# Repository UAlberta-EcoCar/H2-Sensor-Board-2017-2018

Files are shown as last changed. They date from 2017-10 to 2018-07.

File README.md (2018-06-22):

# H2-Sensor-(Safety)-Board
Repository for the hydrogen sensor (safety) board and associated code.

This board is responsible for shutting down the FCC system in case of a H2 leak, E-stop button push or remote-kill signal.

Preliminary documentation (to be moved to Wiki): https://drive.google.com/open?id=1S8betwiyb474213RZoNG3XHaL3DfAaQFg7lT7IdTJPk

Folder on Google Drive with other related files: https://drive.google.com/open?id=1GxiV1qDfL8EswHq86x-2SQPqP8KY5xJN

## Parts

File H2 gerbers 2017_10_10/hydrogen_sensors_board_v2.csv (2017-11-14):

Qty | Value | Device | Package | Parts | Description | PROD_ID | VALUE
6 |  | C-USC0603 | C0603 | C3, C4, C5, C6, C7, C8 | CAPACITOR, American symbol
3 |  | LEDCHIPLED_0805 | CHIPLED_0805 | LED1, LED2, LED3 | LED
1 |  | PINHD-1X3 | 1X03 | JP4 | PIN HEADER
2 | 100k | RESISTOR0603-RES | 0603-RES | R11, R12 | Resistor
7 | 10k | RESISTOR0603-RES | 0603-RES | R1, R5, R6, R7, R8, R9, R10 | Resistor
1 | 1445055-3 | 1445055-3 | 1445055-3 | REMOTE_SENS | Micro MATE-N-LOK Connectors grid 1.5 mm
1 | 16MHz | CRYSTALHC49US | HC49US | Y1 | Various standard crystals. Proven footprints.
3 | 1k | RESISTOR0603-RES | 0603-RES | R2, R3, R4 | Resistor
2 | 22pF | C-USC0603K | C0603K | C1, C2 | CAPACITOR, American symbol
1 | ATMEGA328P_TQFP | ATMEGA328P_TQFP | TQFP32-08 | U1 |  | IC-09069 | ATMEGA328P_TQFP
1 | AVRISP-BOX | AVRISP-BOX | AVRISP-BOX | ISP1 | AVR ISP HEADER
2 | EG4621CT-ND | EG4621CT-ND | EG4621CT-ND | U$2, U$10 | surface mount push putton digikey number EG4621CT-ND
1 | FCC | ETHERNET | A122645-ND | ETH1 | Ethernet port with 2 leds. digikey number A122645-ND
1 | FTDI_DEVICE | FTDI_DEVICE | FTDI_DEVICE_SIDE | JP6 | Connector which mates to FTDI basic or FTDI cable.
4 | MOUNT-PAD-ROUND3.6 | MOUNT-PAD-ROUND3.6 | 3,6-PAD | H1, H2, H3, H4 | MOUNTING PAD, round
1 | MQ-8MQ-8 | MQ-8MQ-8 | MQ-8 | U$1
2 | TE770966 | TE770966 | 2X1-MATE-N-LOCK | U$3, U$9

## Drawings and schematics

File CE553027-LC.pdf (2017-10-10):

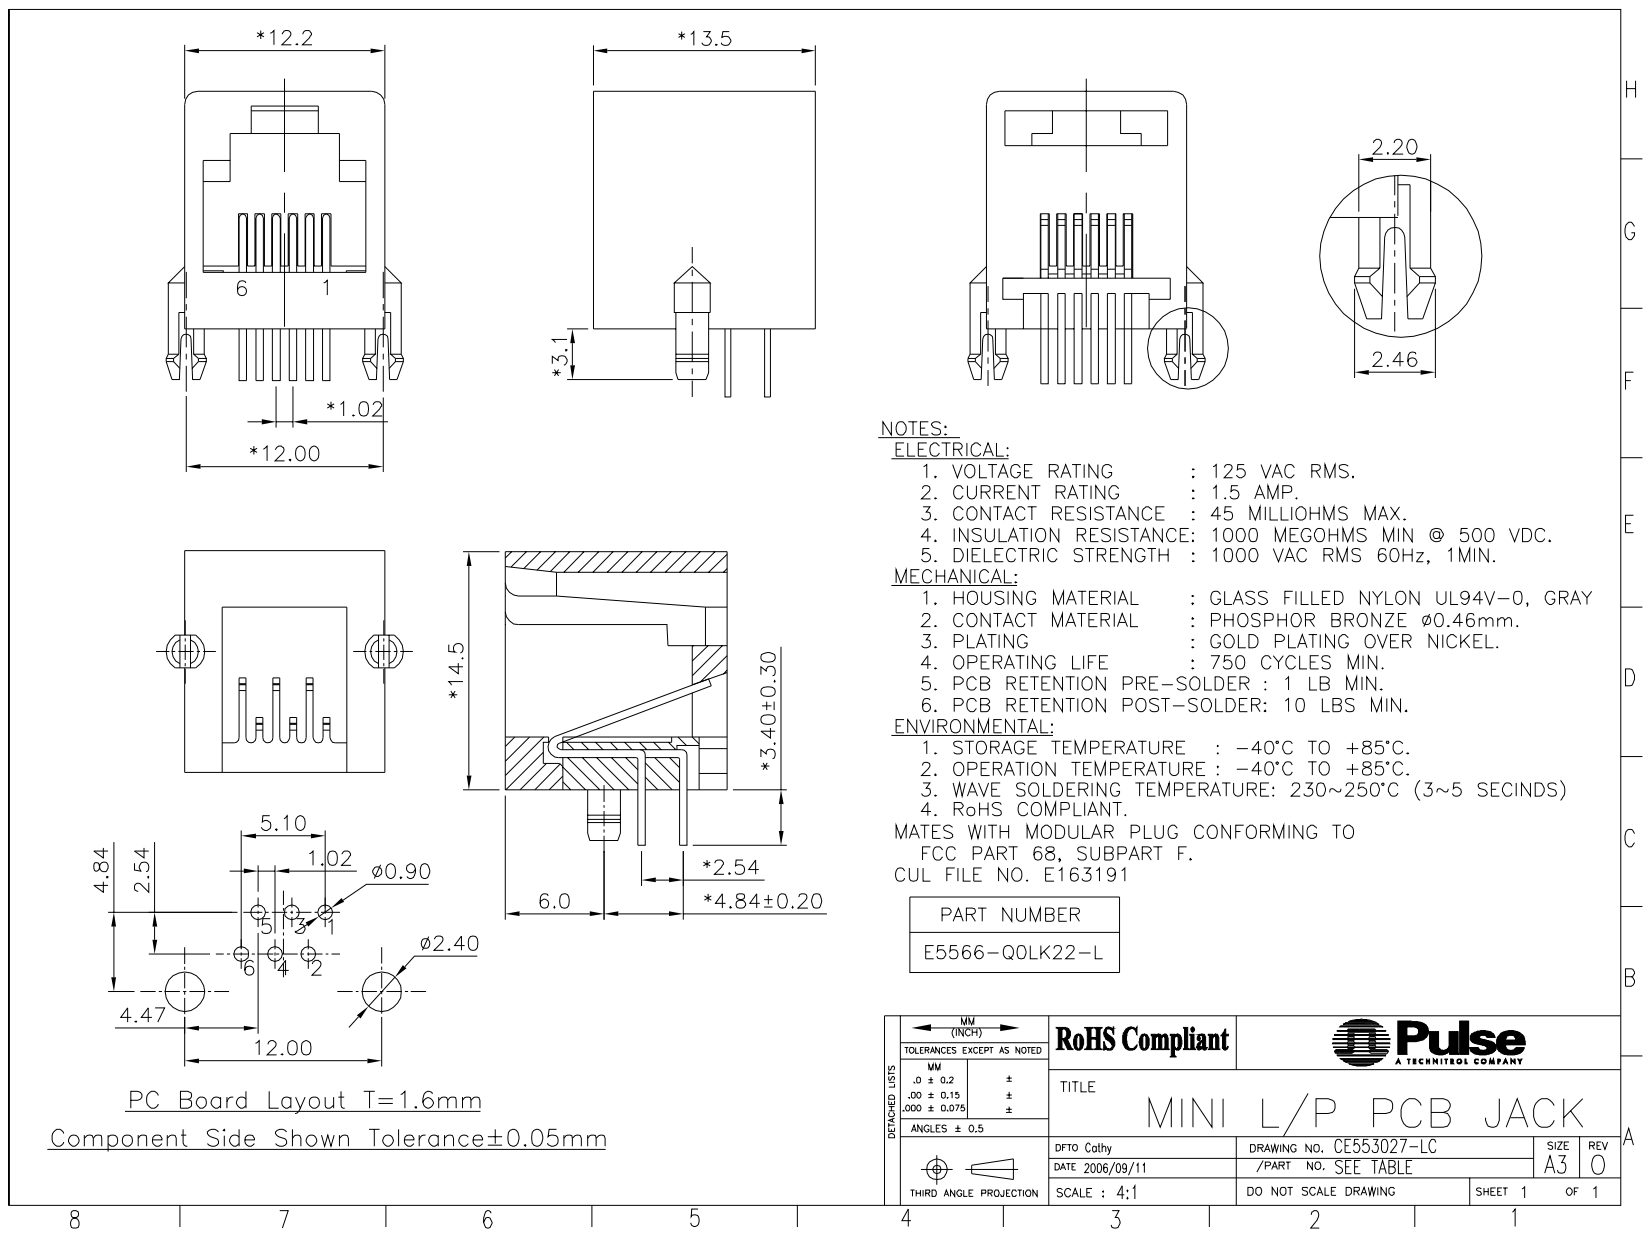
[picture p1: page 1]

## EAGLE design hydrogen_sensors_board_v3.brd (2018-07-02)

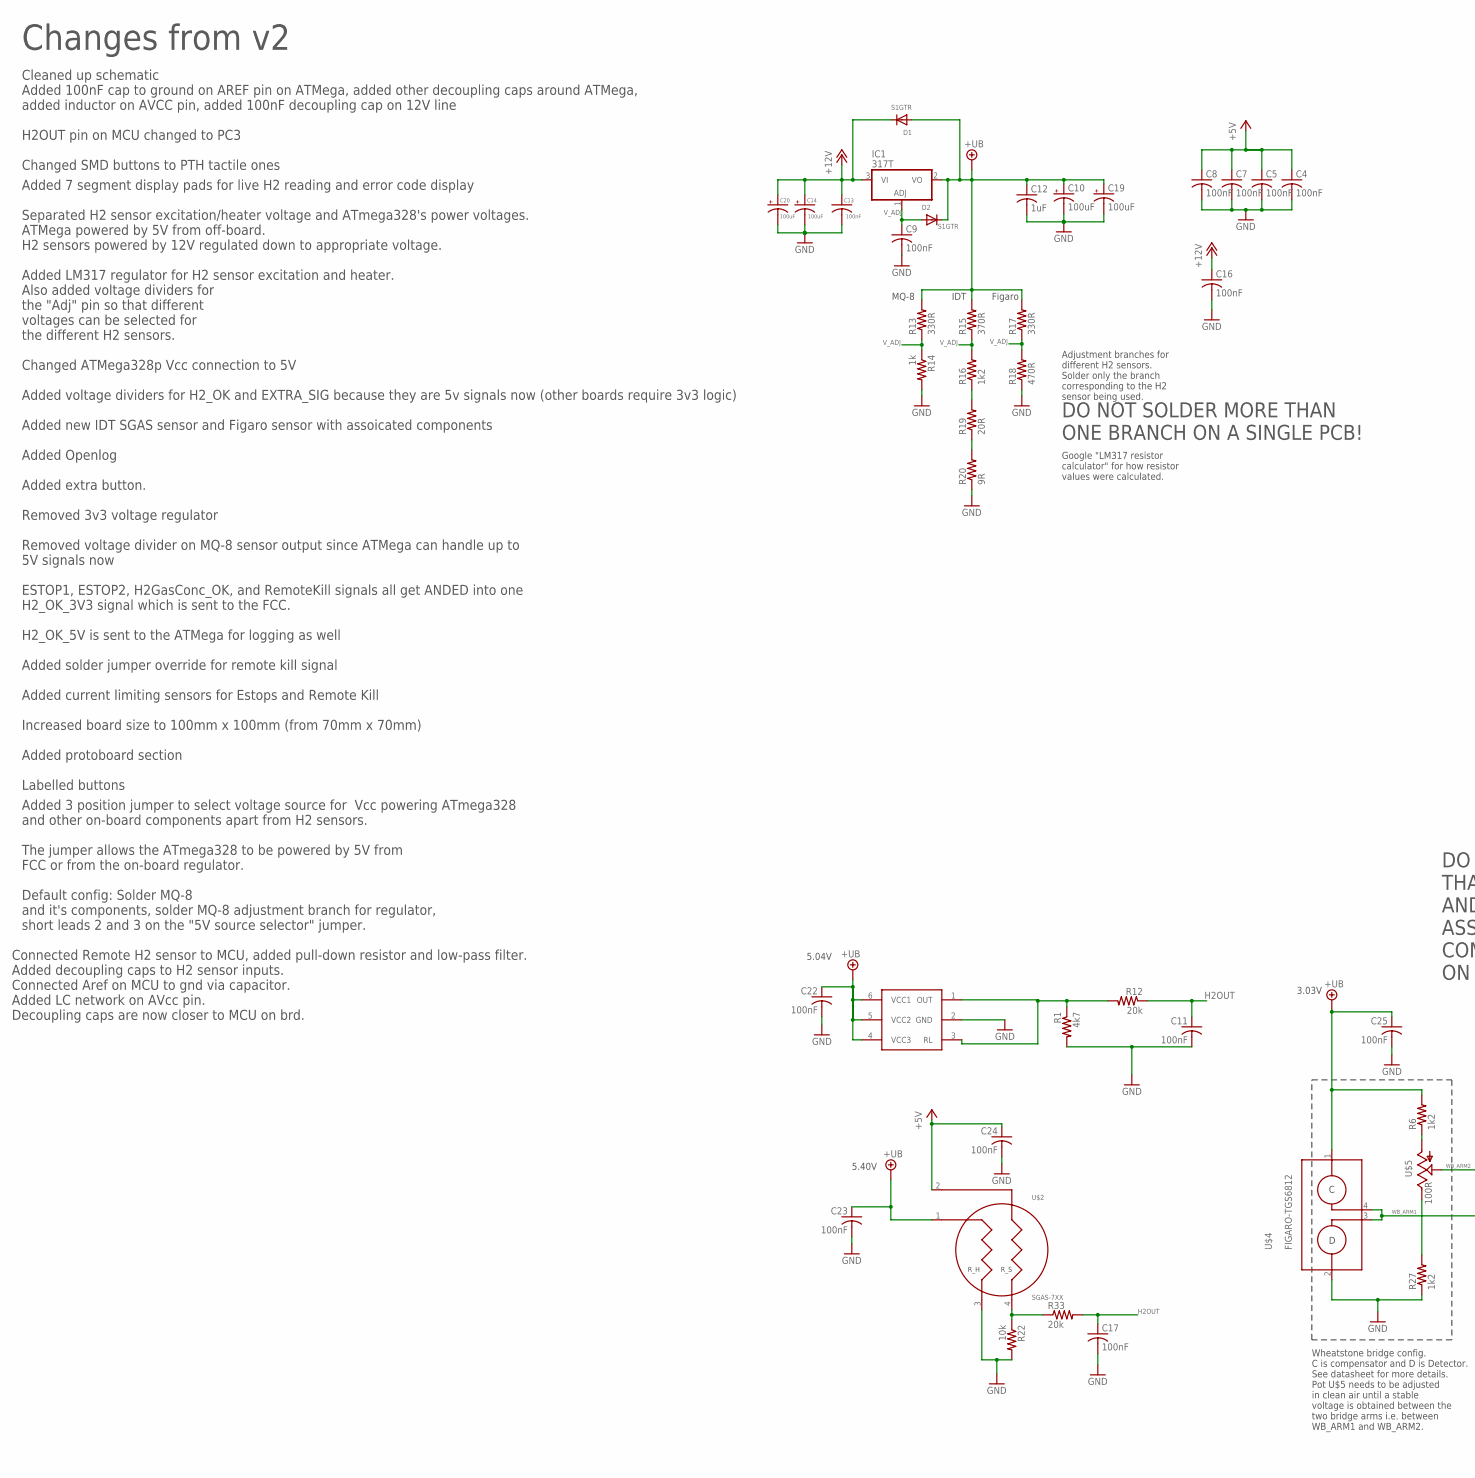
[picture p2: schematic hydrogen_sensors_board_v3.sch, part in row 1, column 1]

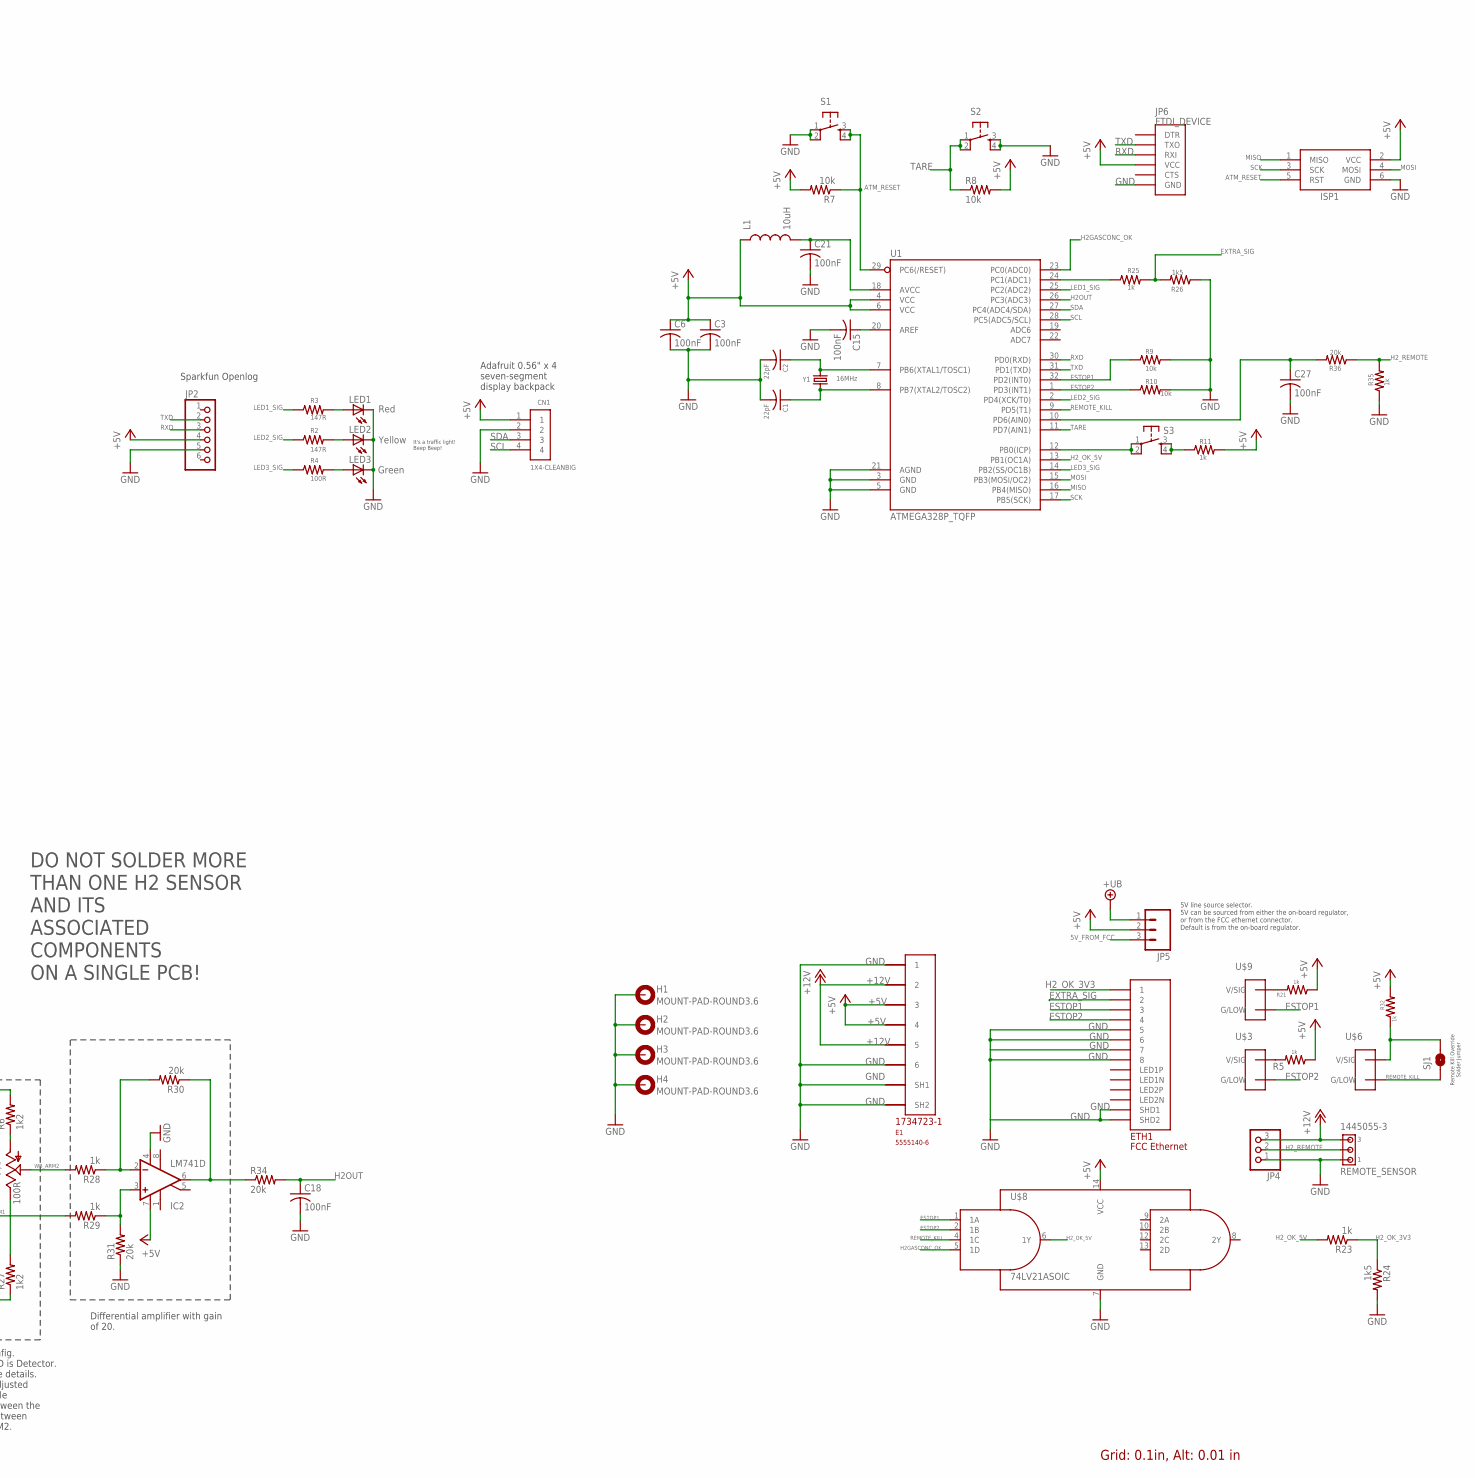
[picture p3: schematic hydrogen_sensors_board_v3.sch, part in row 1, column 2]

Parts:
C1, C2: 22pF; C0603K
C3, C4, C5, C6, C7, C8, C9, C11, C13, C15, C16, C17, C18, C21, C22, C23, C24, C25, C27: 100nF; C0603
C10, C14: 100uF; B/3528-21R
C12: 1uF; C0603
C19, C20: 100uF; CPOL-RADIAL-100UF-25V
CN1: 1X4-CLEANBIG; 1X04-CLEANBIG
D1, D2: S1GTR; SMADIODE
E1: 5555140-6; 1734723-1_RJ11
ETH1: FCC Ethernet; A122645-ND
H1, H2, H3, H4: MOUNT-PAD-ROUND3.6; 3,6-PAD
IC1: 317T; TO220H
IC2: LM741D; SO08
ISP1: AVRISP-BOX
JP2: PINHD-1X6LOCK; 1X06-BIGLOCK
JP4: PINHD-1X3; 1X03
JP5: M03PTH; 1X03
JP6: FTDI_DEVICE; FTDI_DEVICE_SIDE
L1: 10uH; 0603
LED1: Red; CHIPLED_0805
LED2: Yellow; CHIPLED_0805
LED3: Green; CHIPLED_0805
R1: 4k7; 0603-RES
R2, R3: 147R; 0603-RES
R4: 100R; 0603-RES
R5, R11, R14, R21, R23, R25, R28, R29, R32, R35: 1k; 0603-RES
R6, R16, R27: 1k2; 0603-RES
R7, R8, R9, R10, R22: 10k; 0603-RES
R12, R30, R31, R33, R34, R36: 20k; 0603-RES
R13, R17: 330R; 0603-RES
R15: 370R; 0603-RES
R18: 470R; 0603-RES
R19: 20R; 0603-RES
R20: 9R; 0603-RES
R24, R26: 1k5; 0603-RES
REMOTE_SENSOR: 1445055-3
S1, S2, S3: TAC_SWITCHPTH; TACTILE-PTH
SJ1: SOLDERJUMPERNO; SJ_2S-NO
U1: ATMEGA328P_TQFP; TQFP32-08
U$1: MQ-8MQ-8; MQ-8
U$2: SGAS-7XX; TO39
U$3, U$6, U$9: TE770966; 2X1-MATE-N-LOCK
U$4: FIGARO-TGS6812; 4PTH
U$5: 100R; 3362U
U$8: 74LV21ASOIC; SOIC-14
Y1: 16MHz; HC49US

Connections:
5V_FROM_FCC: JP5.3
+5V: C3.1, C4.1, C5.1, C6.1, C7.1, C8.1, C24.1, CN1.1, E1.3, E1.4, IC2.7 (V+), ISP1.2 (VCC), JP2.4, JP5.2, JP6.P$4 (VCC), L1.1, R5.1, R7.2, R8.2, R11.2, R21.1, R32.2, U1.4 (VCC), U1.6 (VCC), U$2.2, U$8.14 (VCC)
+12V: C13.1, C14.+, C16.1, C20.1 (+), D1.C, E1.2, E1.5, IC1.3 (VI), JP4.3, REMOTE_SENSOR.3
+UB: C10.+, C12.1, C19.1 (+), C22.1, C23.1, C25.1, D1.A, D2.C, IC1.2 (VO), JP5.1, R6.2, R13.2, R15.2, R17.2, U$1.4 (VCC3), U$1.5 (VCC2), U$1.6 (VCC1), U$2.1, U$4.1
ATM_RESET: ISP1.5 (RST), R7.1, S1.3, S1.4, U1.29 (PC6(/RESET))
ESTOP1: ETH1.P$3 (3), R9.1, U1.32 (PD2(INT0)), U$8.1 (1A), U$9.CIRCUIT2 (G/LOW)
ESTOP2: ETH1.P$4 (4), R10.1, U1.1 (PD3(INT1)), U$3.CIRCUIT2 (G/LOW), U$8.2 (1B)
EXTRA_SIG: ETH1.P$2 (2), R25.2, R26.2
GND: C1.2, C2.2, C3.2, C4.2, C5.2, C6.2, C7.2, C8.2, C9.2, C10.-, C11.2, C12.2, C13.2, C14.-, C15.2, C16.2, C17.2, C18.2, C19.2 (-), C20.2 (-), C21.2, C22.2, C23.2, C24.2, C25.2, C27.2, CN1.2, E1.1, E1.6, E1.SH1, E1.SH2, ETH1.P$5 (5), ETH1.P$6 (6), ETH1.P$7 (7), ETH1.P$8 (8), ETH1.P$13 (SHD1), ETH1.P$14 (SHD2), H1.B3,6, H2.B3,6, H3.B3,6, H4.B3,6, IC2.4 (V-), ISP1.6 (GND), JP2.5, JP4.1, JP6.P$6 (GND), LED1.C, LED2.C, LED3.C, R1.2, R9.2, R10.2, R14.2, R18.1, R20.1, R22.2, R24.2, R26.1, R27.1, R31.1, R35.1, REMOTE_SENSOR.1, S1.1, S1.2, S2.3, S2.4, U1.3 (GND), U1.5 (GND), U1.21 (AGND), U$1.2 (GND), U$2.3, U$4.2, U$8.7 (GND)
H2GASCONC_OK: U1.23 (PC0(ADC0)), U$8.5 (1D)
H2OUT: C11.1, C17.1, C18.1, R12.1, R33.2, R34.2, U1.26 (PC3(ADC3))
H2_OK_3V3: ETH1.P$1 (1), R23.1, R24.1
H2_OK_5V: R23.2, U1.13 (PB1(OC1A)), U$8.6 (1Y)
H2_REMOTE: JP4.2, R35.2, R36.1, REMOTE_SENSOR.2
LED1_SIG: R3.1, U1.25 (PC2(ADC2))
LED2_SIG: R2.1, U1.2 (PD4(XCK/T0))
LED3_SIG: R4.1, U1.14 (PB2(SS/OC1B))
MISO: ISP1.1 (MISO), U1.16 (PB4(MISO))
MOSI: ISP1.4 (MOSI), U1.15 (PB3(MOSI/OC2))
unnamed: C2.1, U1.7 (PB6(XTAL1/TOSC1)), Y1.2
unnamed: R6.1, U$5.P$3 (A)
unnamed: C1.1, U1.8 (PB7(XTAL2/TOSC2)), Y1.1
unnamed: C15.1, U1.20 (AREF)
unnamed: R22.1, R33.1, U$2.4
unnamed: C27.1, R36.2, U1.10 (PD6(AIN0))
unnamed: LED1.A, R3.2
unnamed: LED2.A, R2.2
unnamed: LED3.A, R4.2
unnamed: R27.2, U$5.P$1 (E)
unnamed: R21.2, U$9.CIRCUIT1 (V/SIG)
unnamed: R25.1, U1.24 (PC1(ADC1))
unnamed: IC2.2 (-IN), R28.1, R30.2
unnamed: R16.1, R19.2
unnamed: S3.1, S3.2, U1.12 (PB0(ICP))
unnamed: R11.1, S3.3, S3.4
unnamed: R19.1, R20.2
unnamed: R1.1, R12.2, U$1.1 (OUT), U$1.3 (RL)
unnamed: IC2.6 (OUT), R30.1, R34.1
unnamed: R5.2, U$3.CIRCUIT1 (V/SIG)
unnamed: IC2.3 (+IN), R29.1, R31.2
unnamed: R32.1, SJ1.2, U$6.CIRCUIT1 (V/SIG)
unnamed: C21.1, L1.2, U1.18 (AVCC)
REMOTE_KILL: SJ1.1, U1.9 (PD5(T1)), U$6.CIRCUIT2 (G/LOW), U$8.4 (1C)
RXD: JP2.3, JP6.P$3 (RXI), U1.30 (PD0(RXD))
SCK: ISP1.3 (SCK), U1.17 (PB5(SCK))
SCL: CN1.4, U1.28 (PC5(ADC5/SCL))
SDA: CN1.3, U1.27 (PC4(ADC4/SDA))
TARE: R8.1, S2.1, S2.2, U1.11 (PD7(AIN1))
TXD: JP2.2, JP6.P$2 (TXO), U1.31 (PD1(TXD))
V_ADJ: C9.1, D2.A, IC1.1 (ADJ), R13.1, R14.1, R15.1, R16.2, R17.1, R18.2
WB_ARM1: R29.2, U$4.3, U$4.4
WB_ARM2: R28.2, U$5.P$2 (S)

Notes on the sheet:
Changes from v2
H2OUT pin on MCU changed to PC3
Changed SMD buttons to PTH tactile ones
Added 7 segment display pads for live H2 reading and error code display
Added LM317 regulator for H2 sensor excitation and heater. Also added voltage dividers for the "Adj" pin so that different voltages can be selected for the different H2 sensors.
Adafruit 0.56" x 4 seven-segment display backpack
Sparkfun Openlog
IDT
MQ-8
Figaro
Changed ATMega328p Vcc connection to 5V
Added voltage dividers for H2_OK and EXTRA_SIG because they are 5v signals now (other boards require 3v3 logic)
Added new IDT SGAS sensor and Figaro sensor with assoicated components
Added Openlog
Added extra button.
Removed 3v3 voltage regulator
Wheatstone bridge config. C is compensator and D is Detector. See datasheet for more details. Pot U$5 needs to be adjusted in clean air until a stable voltage is obtained between the two bridge arms i.e. between WB_ARM1 and WB_ARM2.
Differential amplifier with gain of 20.
3.03V
5.40V
5.04V
Adjustment branches for different H2 sensors. Solder only the branch corresponding to the H2 sensor being used.
DO NOT SOLDER MORE THAN ONE H2 SENSOR AND ITS ASSOCIATED COMPONENTS ON A SINGLE PCB!
It's a traffic light! Beep Beep!
Google "LM317 resistor calculator" for how resistor values were calculated.
Removed voltage divider on MQ-8 sensor output since ATMega can handle up to 5V signals now ESTOP1, ESTOP2, H2GasConc_OK, and RemoteKill signals all get ANDED into one H2_OK_3V3 signal which is sent to the FCC.
Grid: 0.1in, Alt: 0.01 in
Cleaned up schematic Added 100nF cap to ground on AREF pin on ATMega, added other decoupling caps around ATMega, added inductor on AVCC pin, added 100nF decoupling cap on 12V line
Increased board size to 100mm x 100mm (from 70mm x 70mm) Added protoboard section Labelled buttons
Separated H2 sensor excitation/heater voltage and ATmega328's power voltages. ATMega powered by 5V from off-board. H2 sensors powered by 12V regulated down to appropriate voltage.
DO NOT SOLDER MORE THAN ONE BRANCH ON A SINGLE PCB!
H2_OK_5V is sent to the ATMega for logging as well
Added solder jumper override for remote kill signal Added current limiting sensors for Estops and Remote Kill
Added 3 position jumper to select voltage source for Vcc powering ATmega328 and other on-board components apart from H2 sensors. The jumper allows the ATmega328 to be powered by 5V from FCC or from the on-board regulator. Default config: Solder MQ-8 and it's components, solder MQ-8 adjustment branc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
Remote Kill Override Solder Jumper
5V line source selector. 5V can be sourced from either the on-board regulator, or from the FCC ethernet connector. Default is from the on-board regulator.
Connected Remote H2 sensor to MCU, added pull-down resistor and low-pass filter. Added decoupling caps to H2 sensor inputs. Connected Aref on MCU to gnd via capacitor. Added LC network on AVcc pin. Decoupling caps are now closer to MCU on brd.

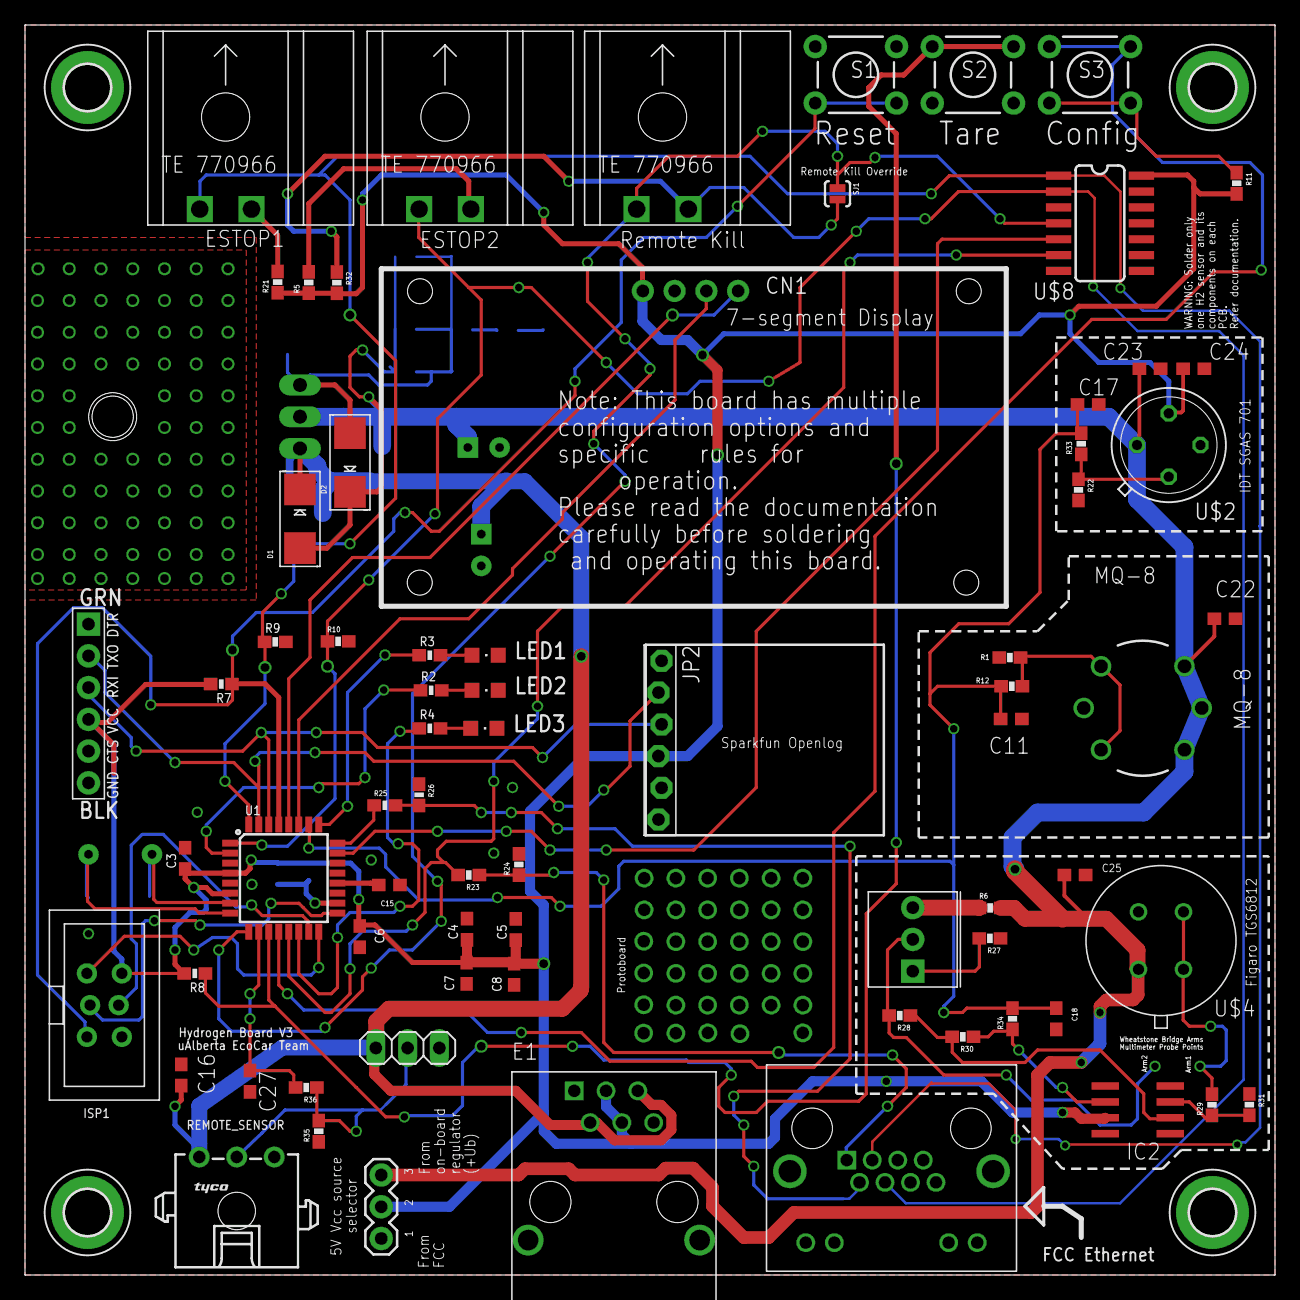
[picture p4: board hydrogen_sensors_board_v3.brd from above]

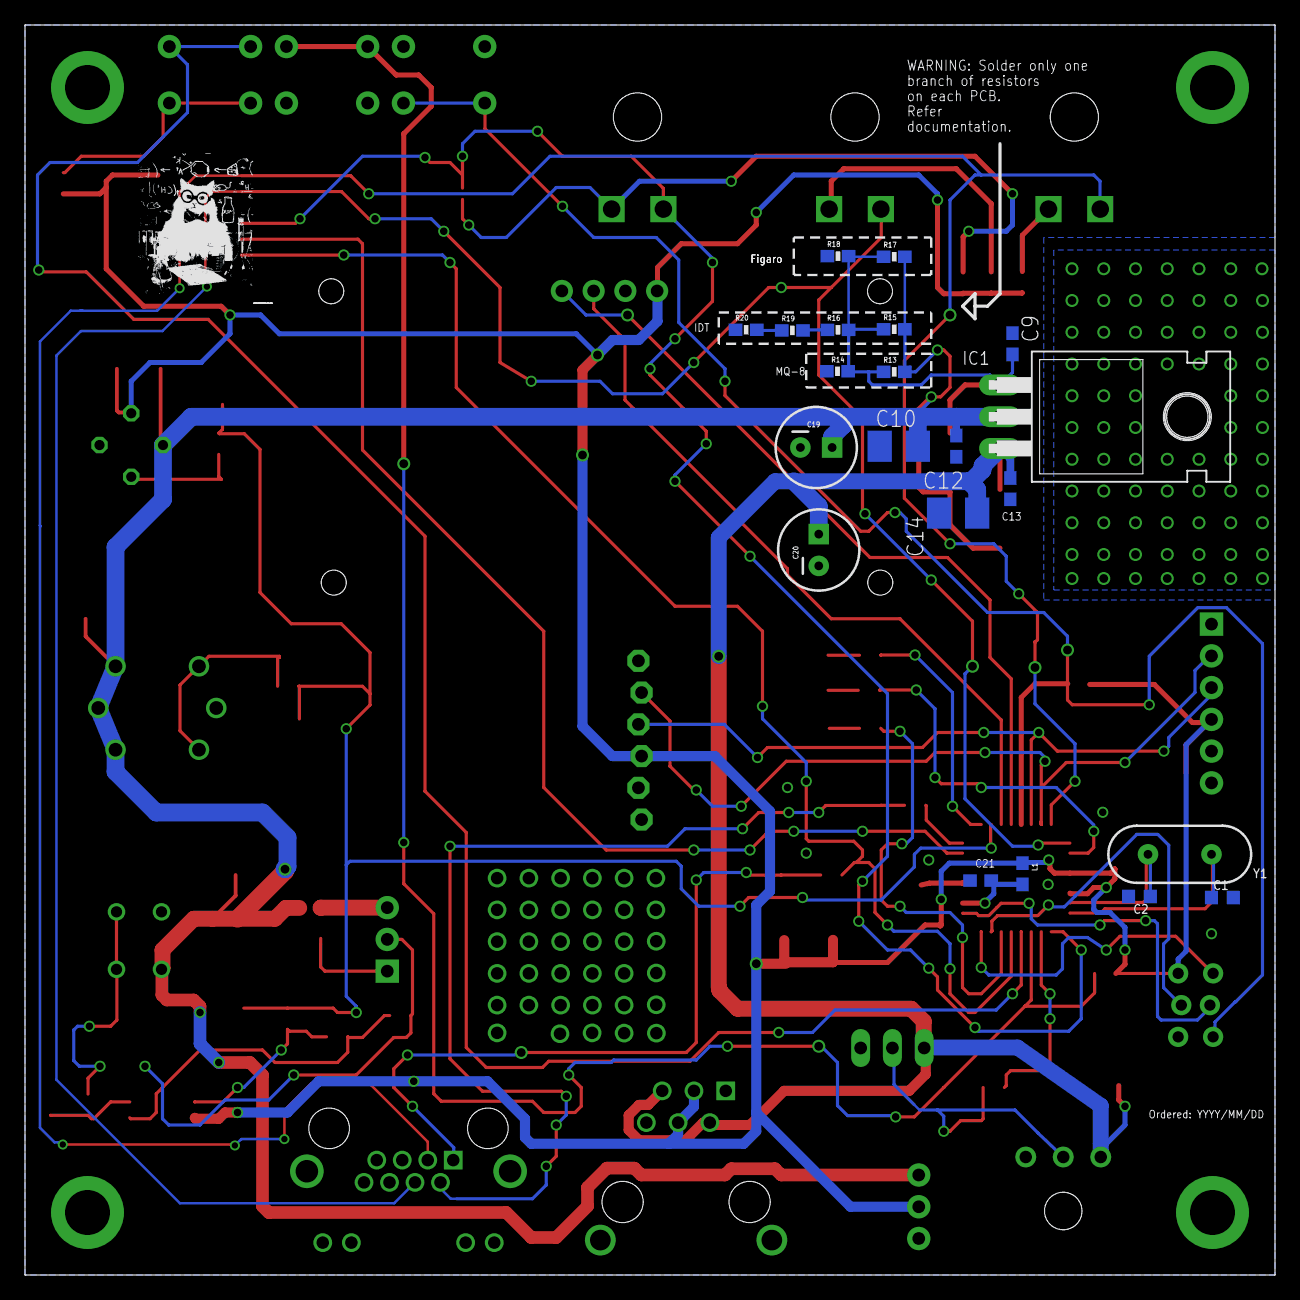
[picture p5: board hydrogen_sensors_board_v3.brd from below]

Board: 2 copper layers, 100.0 x 100.0 mm, 97 parts (21 on the bottom side), 51 nets.

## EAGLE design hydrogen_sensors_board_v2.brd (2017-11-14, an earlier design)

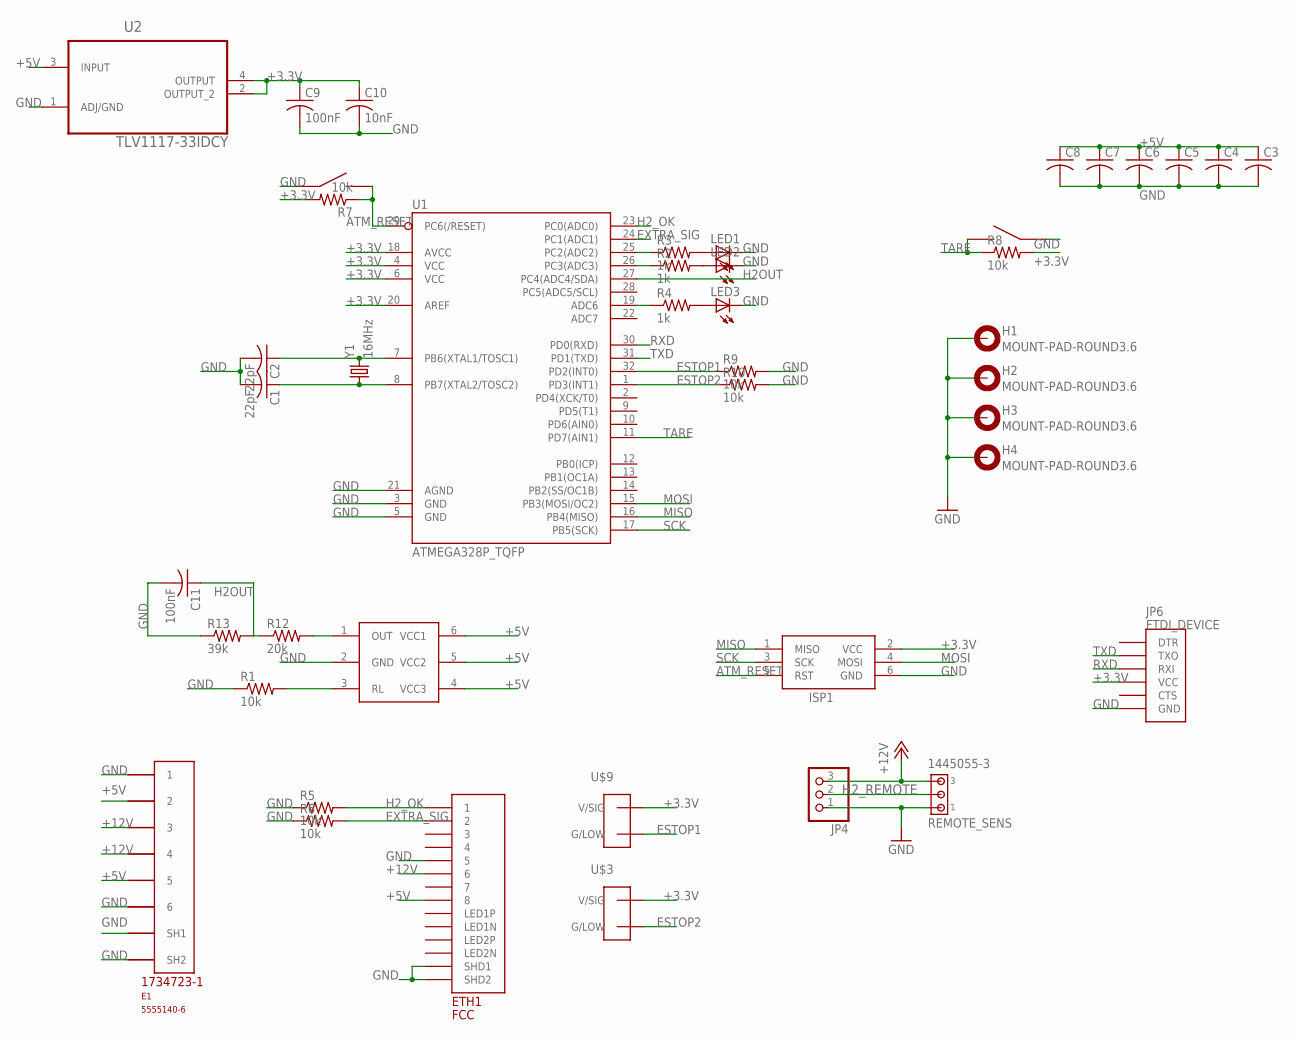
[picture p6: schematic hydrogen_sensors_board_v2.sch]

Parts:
C1, C2: 22pF; C0603K
C3, C4, C5, C6, C7, C8: C-USC0603; C0603
C9, C11: 100nF; C0603
C10: 10nF; C0603
E1: 5555140-6; 1734723-1_RJ11
ETH1: FCC; A122645-ND
H1, H2, H3, H4: MOUNT-PAD-ROUND3.6; 3,6-PAD
ISP1: AVRISP-BOX
JP4: PINHD-1X3; 1X03
JP6: FTDI_DEVICE; FTDI_DEVICE_SIDE
LED1, LED2, LED3: LEDCHIPLED_0805; CHIPLED_0805
R1, R5, R6, R7, R8, R9, R10: 10k; 0603-RES
R2, R3, R4: 1k; 0603-RES
R12: 20k; 0603-RES
R13: 39k; 0603-RES
REMOTE_SENS: 1445055-3
U1: ATMEGA328P_TQFP; TQFP32-08
U2: TLV1117-33IDCY; SOT230P700X180-4N
U$1: MQ-8MQ-8; MQ-8
U$2, U$10: EG4621CT-ND
U$3, U$9: TE770966; 2X1-MATE-N-LOCK
Y1: 16MHz; HC49US

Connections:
+3.3V: C9.1, C10.1, ISP1.2 (VCC), JP6.P$4 (VCC), R7.2, R8.2, U1.4 (VCC), U1.6 (VCC), U1.18 (AVCC), U1.20 (AREF), U2.2 (OUTPUT_2), U2.4 (OUTPUT), U$3.CIRCUIT1 (V/SIG), U$9.CIRCUIT1 (V/SIG)
+5V: C3.1, C4.1, C5.1, C6.1, C7.1, C8.1, E1.2, E1.5, ETH1.P$8 (8), U2.3 (INPUT), U$1.4 (VCC3), U$1.5 (VCC2), U$1.6 (VCC1)
+12V: E1.3, E1.4, ETH1.P$6 (6), JP4.3, REMOTE_SENS.3
ATM_RESET: ISP1.5 (RST), R7.1, U1.29 (PC6(/RESET)), U$10.P$3, U$10.P$4
ESTOP1: R9.1, U1.32 (PD2(INT0)), U$9.CIRCUIT2 (G/LOW)
ESTOP2: R10.1, U1.1 (PD3(INT1)), U$3.CIRCUIT2 (G/LOW)
EXTRA_SIG: ETH1.P$2 (2), R6.2, U1.24 (PC1(ADC1))
GND: C1.2, C2.2, C3.2, C4.2, C5.2, C6.2, C7.2, C8.2, C9.2, C10.2, C11.2, E1.1, E1.6, E1.SH1, E1.SH2, ETH1.P$5 (5), ETH1.P$13 (SHD1), ETH1.P$14 (SHD2), H1.B3,6, H2.B3,6, H3.B3,6, H4.B3,6, ISP1.6 (GND), JP4.1, JP6.P$6 (GND), LED1.C, LED2.C, LED3.C, R1.1, R5.1, R6.1, R9.2, R10.2, R13.1, REMOTE_SENS.1, U1.3 (GND), U1.5 (GND), U1.21 (AGND), U2.1 (ADJ/GND), U$1.2 (GND), U$2.P$1, U$2.P$2, U$10.P$1, U$10.P$2
H2OUT: C11.1, R12.1, R13.2, U1.27 (PC4(ADC4/SDA))
H2_OK: ETH1.P$1 (1), R5.2, U1.23 (PC0(ADC0))
H2_REMOTE: JP4.2, REMOTE_SENS.2
MISO: ISP1.1 (MISO), U1.16 (PB4(MISO))
MOSI: ISP1.4 (MOSI), U1.15 (PB3(MOSI/OC2))
unnamed: C2.1, U1.7 (PB6(XTAL1/TOSC1)), Y1.2
unnamed: R1.2, U$1.3 (RL)
unnamed: C1.1, U1.8 (PB7(XTAL2/TOSC2)), Y1.1
unnamed: R3.1, U1.25 (PC2(ADC2))
unnamed: R2.1, U1.26 (PC3(ADC3))
unnamed: R4.1, U1.19 (ADC6)
unnamed: LED1.A, R3.2
unnamed: LED2.A, R2.2
unnamed: LED3.A, R4.2
unnamed: R12.2, U$1.1 (OUT)
RXD: JP6.P$3 (RXI), U1.30 (PD0(RXD))
SCK: ISP1.3 (SCK), U1.17 (PB5(SCK))
TARE: R8.1, U1.11 (PD7(AIN1)), U$2.P$3, U$2.P$4
TXD: JP6.P$2 (TXO), U1.31 (PD1(TXD))

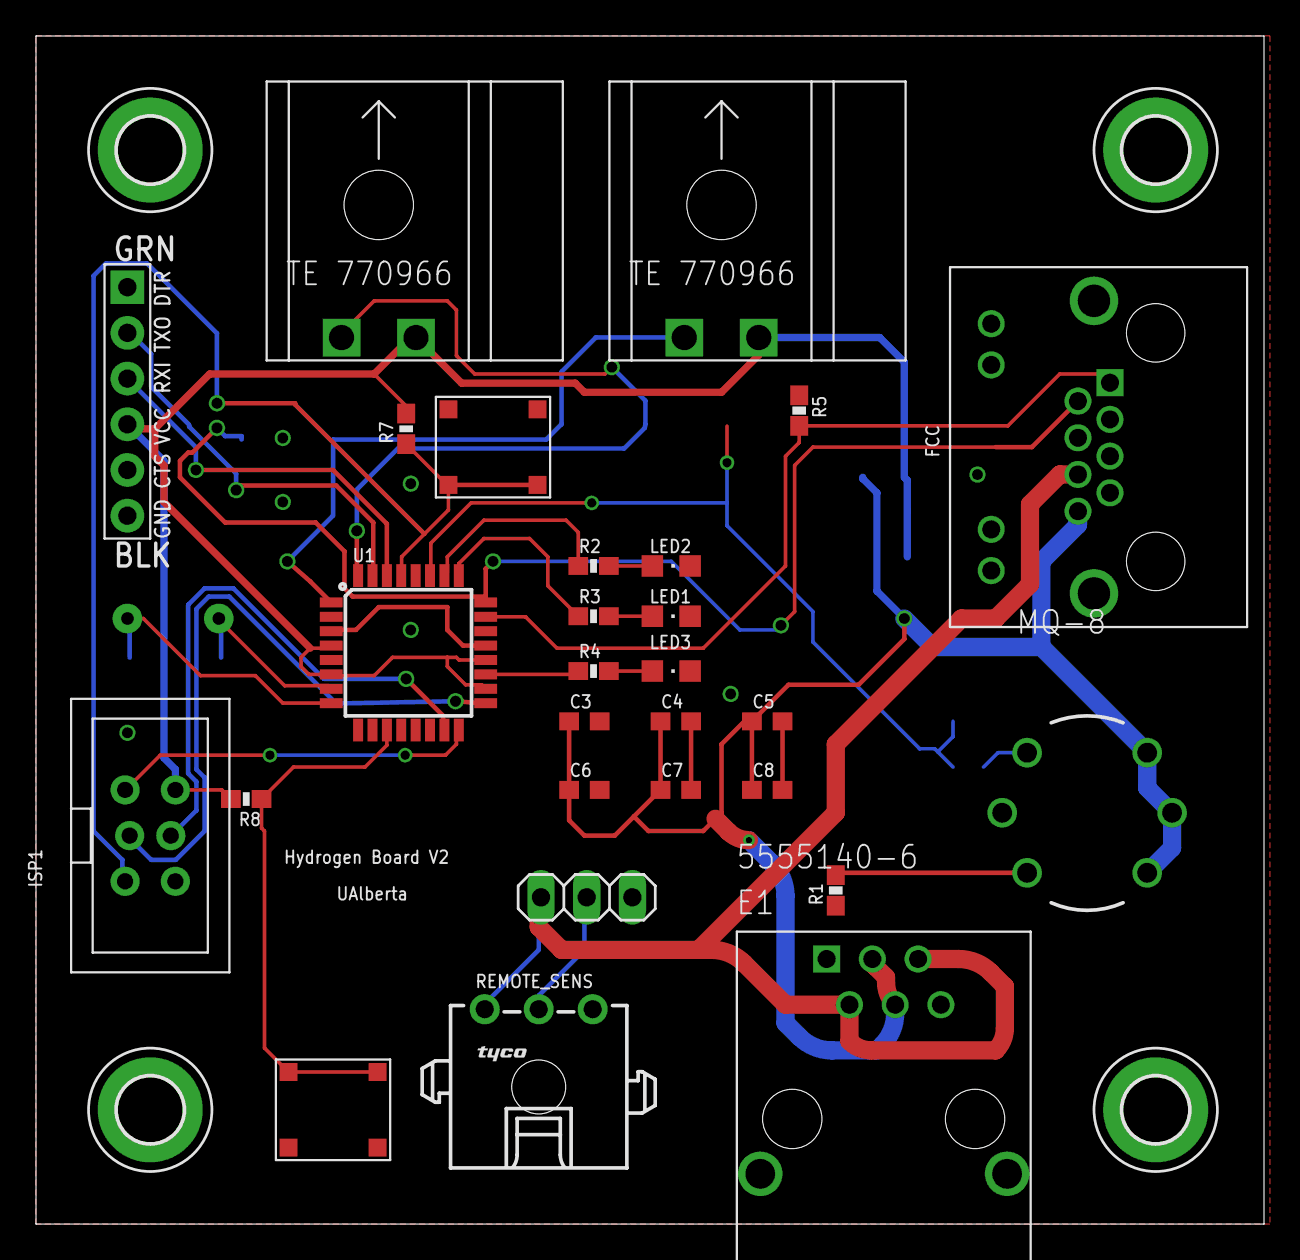
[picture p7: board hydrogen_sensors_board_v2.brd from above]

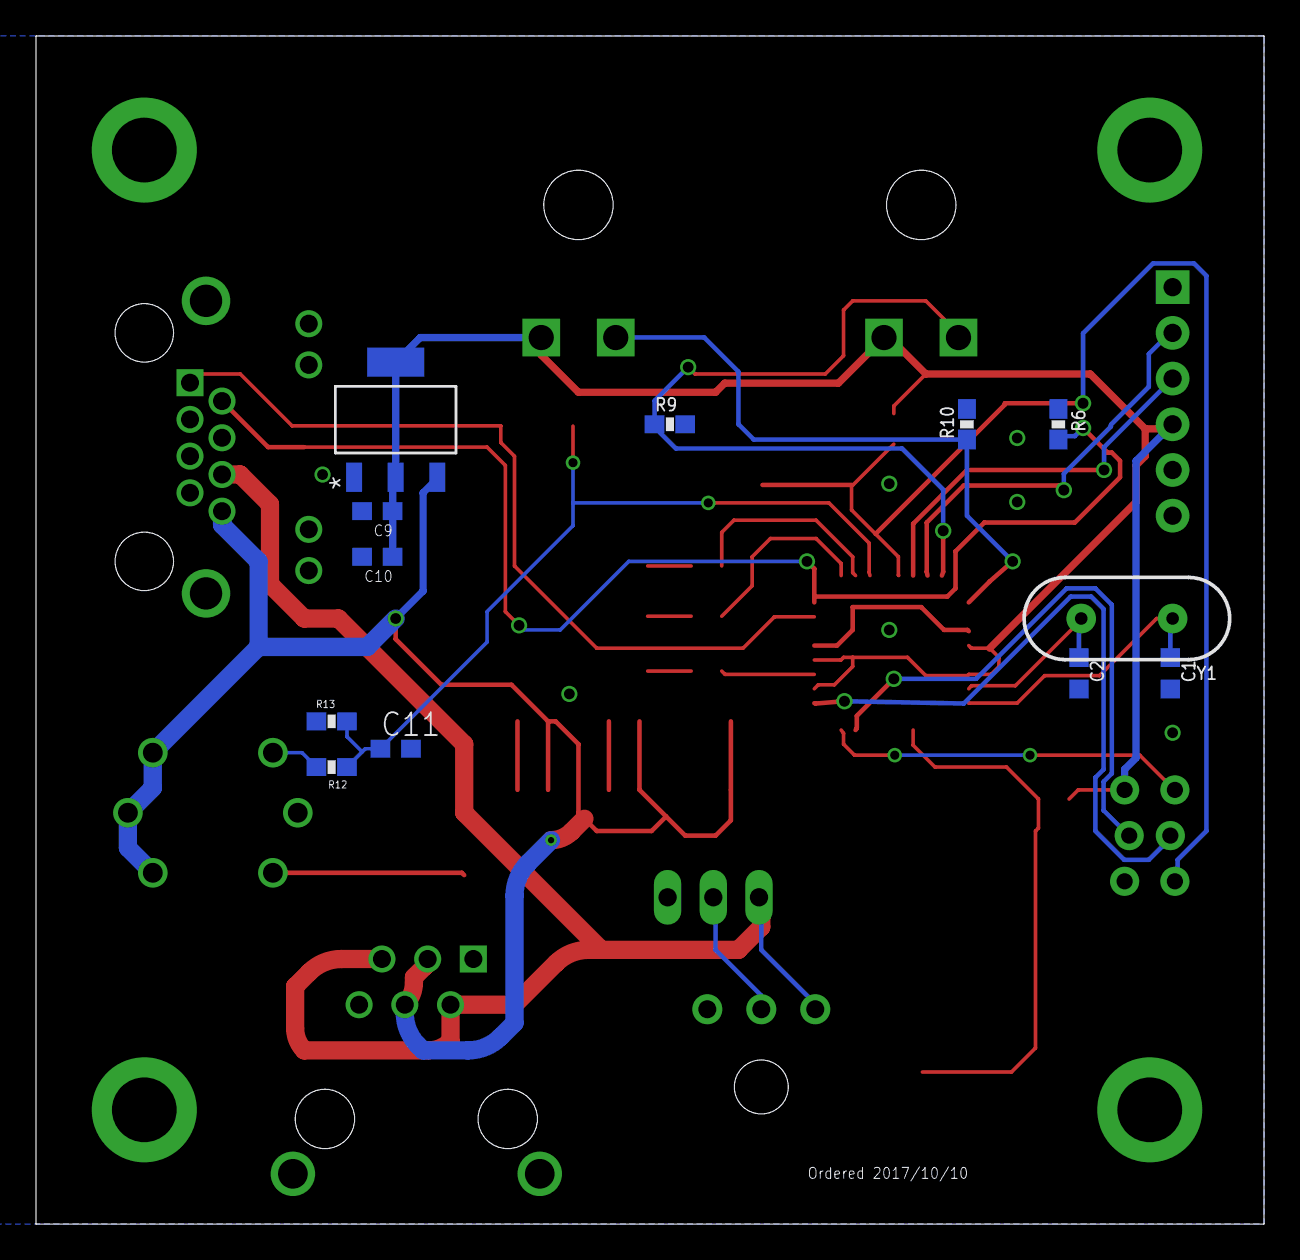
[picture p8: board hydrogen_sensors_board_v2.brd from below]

Board: 2 copper layers, 68.2 x 66.0 mm, 44 parts (12 on the bottom side), 27 nets.

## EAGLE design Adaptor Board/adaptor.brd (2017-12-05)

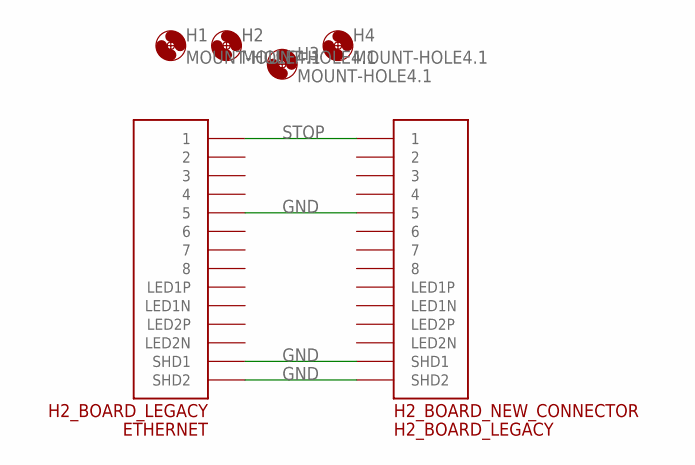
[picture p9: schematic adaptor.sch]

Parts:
H1, H2, H3, H4: MOUNT-HOLE4.1; 4,1
H2_BOARD_LEGACY: ETHERNET; A122645-ND
H2_BOARD_NEW_CONNECTOR: H2_BOARD_LEGACY; A122645-ND

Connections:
GND: H2_BOARD_LEGACY.P$5 (5), H2_BOARD_LEGACY.P$13 (SHD1), H2_BOARD_LEGACY.P$14 (SHD2), H2_BOARD_NEW_CONNECTOR.P$5 (5), H2_BOARD_NEW_CONNECTOR.P$13 (SHD1), H2_BOARD_NEW_CONNECTOR.P$14 (SHD2)
STOP: H2_BOARD_LEGACY.P$1 (1), H2_BOARD_NEW_CONNECTOR.P$1 (1)

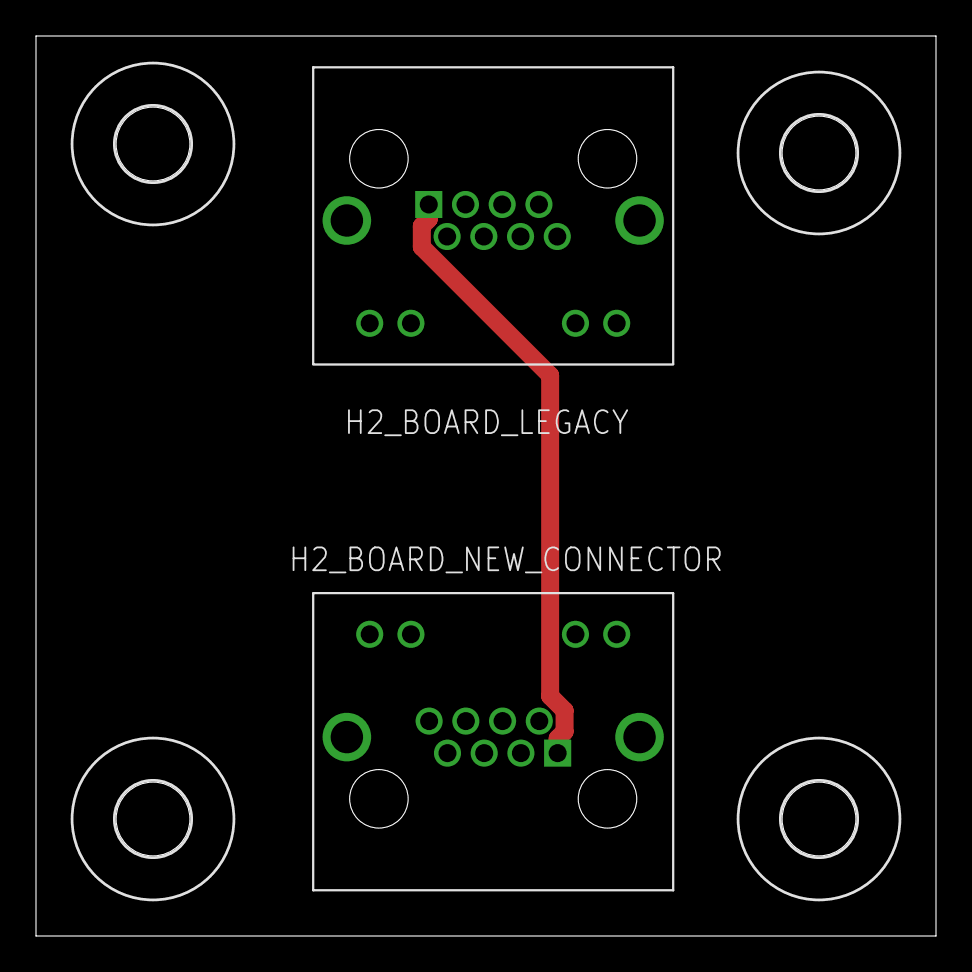
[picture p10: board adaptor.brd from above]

Board: 2 copper layers, 50.0 x 50.0 mm, 6 parts (0 on the bottom side), 2 nets.

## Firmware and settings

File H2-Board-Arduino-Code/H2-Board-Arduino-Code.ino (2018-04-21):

#include <RingBuf.h>

int H2_OK_PIN = A0; // Initialize variable for H2-board output pin
int H2_SENSOR_PIN = A4; // Initialize variable for H2-sensor output pin
int H2_LED1_PIN = A2; // Initialize variable for H2 indicator LED (LED1 on board--red)

int ESTOP1_PIN = 2; // Initialize variable for ESTOP1 pin
int ESTOP2_PIN = 3; // Initialize variable for ESTOP2 pin
int ESTOP_LED2_PIN = A3; // Initialize variable for ESTOP indicator LED (LED2 on board--blue)

int h2_sensor_value; // Initialize input variable for H2_SENSOR_PIN
int h2_sensor_cutoff = 95; // Initialize variable to store cutoff value for H2-sensor
int h2_sensor_avg;
bool estop1_value; // Initialize input variable for ESTOP1_PIN
bool estop2_value; // Initialize input variable for ESTOP2_PIN

RingBufC buf(10*sizeof(int),10);


void setup() {
  pinMode(H2_OK_PIN, OUTPUT); // Set H2_OK_PIN to output
  pinMode(H2_LED1_PIN, OUTPUT); // Set H2_LED1_PIN to output
  pinMode(ESTOP_LED2_PIN, OUTPUT); // Set ESTOP_LED2_PIN to output
  pinMode(H2_SENSOR_PIN, INPUT); // Set H2_SENSOR_PIN to input
  pinMode(ESTOP1_PIN, INPUT); // Set ESTOP1_PIN to input
  pinMode(ESTOP2_PIN, INPUT); // Set ESTOP2_PIN to input
  
  Serial.begin(115200); // Begin serial monitor output -- for testing and setting a value for h2_sensor_cutoff (remove later)
}

void loop() {
  int garbage = 0;
  h2_sensor_value = analogRead(H2_SENSOR_PIN); // Read value from H2_SENSOR_PIN and store in h2_sensor_value
  estop1_value = digitalRead(ESTOP1_PIN); // Read value from ESTOP1_PIN and store in estop1_value
  estop2_value = digitalRead(ESTOP2_PIN); // Read value from ESTOP2_PIN and store in estop2_value

  buf.add(&h2_sensor_value);

  if(buf.numElements() < 10){
    return;
  }

  h2_sensor_avg = getBufAvg(buf);

  if ((estop1_value == LOW) || (estop2_value == LOW) || (h2_sensor_avg >= h2_sensor_cutoff))
  {
    digitalWrite(H2_OK_PIN, LOW); // If either ESTOP is pushed or excess hydrogen is sensed, shut down system
  }
  else
  {
    digitalWrite(H2_OK_PIN, HIGH); // If everything ok, keep H2 pin set to ok
  }

  if ((estop1_value == LOW) || (estop2_value == LOW)) // If either ESTOP is pushed turn on indicator LED
  {
    digitalWrite(ESTOP_LED2_PIN, HIGH); // Turn on blue LED
  }
  else
  {
    digitalWrite(ESTOP_LED2_PIN, LOW); // If no ESTOPs are pushed keep blue LED off
  }



  if (h2_sensor_avg >= h2_sensor_cutoff) // If excess hydrogen is sensed, turn on H2 indicator LED
  {
    digitalWrite(H2_LED1_PIN, HIGH); // Turn on red LED
  }
  else
  {
    digitalWrite(H2_LED1_PIN, LOW); // If no excess hydrogen, keep red LED off
  }

  buf.pull(&garbage);

  Serial.println(h2_sensor_avg); // Print read value from H2 sensor to serial monitor -- for testing and setting a suitable value for h2_sensor_cutoff (remove later)
  delay(50); // Delay reading to make serial monitor easier to track (remove later)

}

int getBufAvg(RingBufC buf){
  int avg = 0;
  int num_elements = buf.numElements();

  for(int i=0;i<num_elements;i++){
    avg += *((int*)buf.peek(i));
  }
}

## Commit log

2017-10-10 Full Board Design Copied From Fuel Cell Controller Repo
    [hydrogen_sensors_board_v2.GBL, hydrogen_sensors_board_v2.GBO, hydrogen_sensors_board_v2.GBP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]
2017-10-21 Small Board Clean up
    [hydrogen_sensors_board_v2.brd]
2017-11-14 changed a resistor value to a standard value
    [hydrogen_sensors_board_v2.GBL, hydrogen_sensors_board_v2.GBO, hydrogen_sensors_board_v2.GBP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]
2017-11-25 Revert "fixed ignore file"
    This reverts commit 2d951463a15c837006f78e97446e8d7e802643ae, reversing
    changes made to 8ab7b9f3e779fa946bec7fd04fad7310f99952af.
    [hydrogen_sensors_board_v2.brd]
2017-12-05 Gerbers Generated
    [adaptor.brd, adaptor.sch]
2018-03-10 Create H2-Board-Arduino-Code
    Arduino code for H2-Sensor-Board. The lines of code used for the serial monitor to find a value for h2_sensor_cutoff should be removed after a value has been chosen -- these are marked with "(remove 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
2018-04-21 adding moving average filter
2018-06-16 Added v3 of Hydrogen Sensor/Safety Board
    Cleaned up schematic
    Lots of overlapping names, text, untidy and hard to read items have been
    cleaned up.
    ATMega (MCU) pin changes
    H2OUT signal from H2 sensor(s) is on pin 26
    LED1, LED2, LED3, are on pins 25,2,14 respectively
    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
    [hydrogen_sensors_board_v3.brd, hydrogen_sensors_board_v3.sch]
2018-06-17 Added decoupling caps and inductor
    100nF cap moved closer to VCC pin on right side of ATmega, added
    inductor on AVCC line which then connects to 5V line. This is for more
    accurate ADC measurements as noted in datasheet. 100nF cap also added to
    12V line for decoupling.
    [hydrogen_sensors_board_v3.brd, hydrogen_sensors_board_v3.sch]
2018-06-20 Noise filtering, R_s sensor voltage updated, updated README, brd and sch cleaned up
    Noise filtering
    Added low-pass filters to IDT SGAS and Figaro sensors.
    R_s sensor voltage updated
    IDT SGAS sensor's R_s voltage changed to 5V Vcc from 5.4V Regulator
    output (Ub). Datasheet says max permitted voltage for R_s is 5V.
    Updated README
    Links to preliminary documentation and folder on Gdrive with other
    files.
    brd and sch cleaned up
    Buttons moved a bit to the left, MQ-8 sensor schematic mirrored to match
    other sensors.
    [hydrogen_sensors_board_v3.brd, hydrogen_sensors_board_v3.sch]
2018-06-22 Inductor value, multimeter probe points, README
    Inductor value
    Changed inductor value on MCU AVCC pin to 10uH per datasheet
    recommendation.
    Multimeter probe points
    Added two probe points for the two arms of the Wheatstone bridge for the
    Figaro H2 sensor circuit. Will make it easy to measure voltage between
    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
    [hydrogen_sensors_board_v3.brd, hydrogen_sensors_board_v3.sch]
2018-06-22 Added more decoupling caps
    Added 100uF electrolytic, through-hole caps to regulator input and output. These caps are in addition to the ceramic and tantalum caps already present. Also added one more 100nF cap near the MCU.
    [hydrogen_sensors_board_v3.brd, hydrogen_sensors_board_v3.sch]
2018-06-24 Decoupling caps, remote H2 sensor, MCU LC network, protection diodes, Figaro op-amp
    - Decoupling caps
    Added decoupling caps to H2 sensor inputs (100nF)
    - Remote H2 sensor
    Connected remote H2 sensor to MCU. Was disconnected previously. Also added pull-down resistor and low-pass filter
    - MCU LC network
    Corrected errors in LC network on AVcc pin of MCU. Capacitor was connected on Vcc side of inductor. It has now been connected to AVcc pin side of inductor as shown in the ATmega datasheet.
    - Protection diodes
    Added protection diodes to on-board regulator as per datasheet.
    - Figaro op-amp
    Corrected errors in Figaro H2 sensor's op-amp circuit. + and - lines were switched and R31 was switched t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
    [hydrogen_sensors_board_v3.brd, hydrogen_sensors_board_v3.sch]
2018-06-25 Moved MQ-8 resistors and capacitor, updated change-log
    Moved components a bit so that they don't overlap with the MQ-8 H2 sensor.
    Updated changelog in .sch file
    [hydrogen_sensors_board_v3.brd, hydrogen_sensors_board_v3.sch]
2018-07-01 updated rj 11 part. added signals to ethernet connector
    [hydrogen_sensors_board_v3.brd, hydrogen_sensors_board_v3.sch]
2018-07-02 routed ESTOP Signal
    [hydrogen_sensors_board_v3.brd]

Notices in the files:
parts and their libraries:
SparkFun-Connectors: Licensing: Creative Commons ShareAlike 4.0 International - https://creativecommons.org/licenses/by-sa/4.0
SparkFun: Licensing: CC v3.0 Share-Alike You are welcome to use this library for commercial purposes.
